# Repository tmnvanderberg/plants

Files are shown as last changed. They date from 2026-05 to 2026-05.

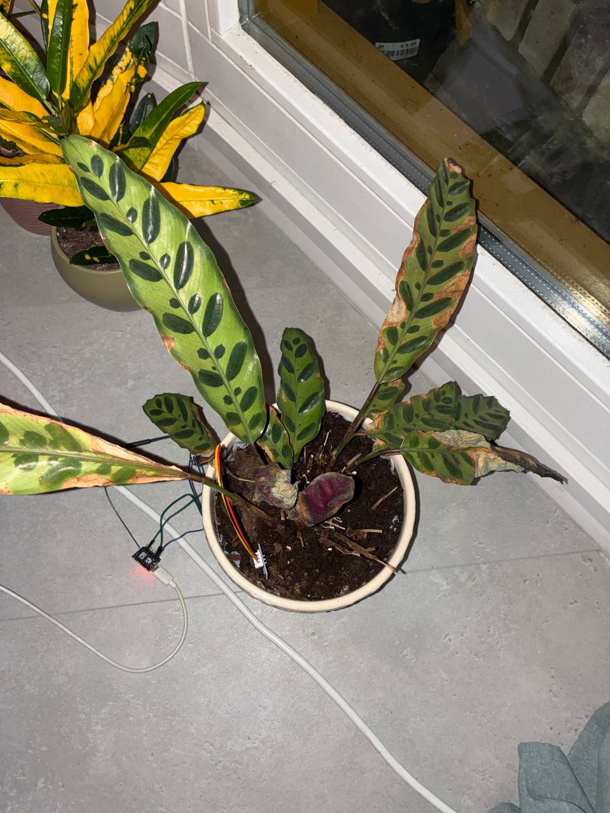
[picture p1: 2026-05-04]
backend/images/plant-node-01.jpg

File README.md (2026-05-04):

# plants

DIY moisture + light monitoring for ~15 plants (10 on a covered Zwolle balcony, ~5 indoors). ESPHome devices reporting to a Pi running Mosquitto + InfluxDB + Grafana.

## Status

**Phase A** — receiver bring-up and BLE-through-windows feasibility test.

## Layout

```
esphome/        device firmware (ESPHome YAML)
  common/       shared config blocks
  receiver.yaml ESP32-WROOM-32 receiver
backend/        Pi services (docker-compose)
docs/           BOM, wiring, phase plans
CLAUDE.md       conventions for LLM-assisted edits
```

## Quick start

### Receiver (Phase A)

```sh
cd esphome
cp secrets.yaml.example secrets.yaml      # fill in WiFi + generated keys
esphome run receiver.yaml                 # initial flash via USB
esphome run receiver.yaml --device plant-receiver.local   # OTA from now on
```

### Backend (Pi)

```sh
cd backend
cp .env.example .env                      # fill in
docker compose up -d                      # or `docker-compose up -d` on Bookworm (apt ships compose v1)
```

Grafana on `:3000`, InfluxDB on `:8086`, Mosquitto on `:1883`.

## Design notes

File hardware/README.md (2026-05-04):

# Hardware design — sensor node

Per-node hardware for the 15× plant monitoring deployment. One identical
node per pot, addressed `plant-node-01` … `plant-node-15`.

## Bill of materials (per node)

| Ref | Part | Notes |
|-----|---|---|
| MCU | ESP32-C3 SuperMini Plus, soldered male headers | 2×8 pin layout, USB-C |
| Light sensor | GY-30 BH1750 module | 1×5 male header replaced with 5-pin JST-XH; see assembly |
| BH1750 cable | JST-XH 5-pin, 5-wire, both ends crimped | stock part |
| Moisture sensor | Capacitive Soil Moisture Sensor with cable (Soldered) | ships with 3-pin cable |
| Battery | 3× AA alkaline holder, integrated switch | nominal 4.5 V, EOL ~3.6 V |
| Carrier PCB | custom, see below | one per node |
| Enclosure | houses carrier + battery holder; BH1750 mounts outside | TBD |

## Power

- 3× AA → carrier `J3` (2-pin JST-PH) → ESP32-C3 `VBUS` pin (silkscreen `5V`).
- C3's onboard LDO (ME6217A33) regulates to 3.3 V; ~150 mV dropout at sleep
  currents holds the rail solid down to a depleted 3.6 V pack.
- Both sensor VCCs share a single switch (not connected to `+3V3` directly):
  - Moisture + BH1750 VCC ← GPIO0 (`SENSOR_PWR`)
  - Combined draw is well under the 40 mA GPIO source limit, so no MOSFET.
- Battery monitor: 1 MΩ / 1 MΩ divider from VBAT to GND, midpoint to GPIO4,
  with 100 nF (`C1`) from the midpoint to GND so the ADC's sample-and-hold
  sees a low AC source impedance.
- USB-C and battery share `VSYS` on the C3. The C3 has a Schottky blocking
  battery → USB-host backfeed, but no diode the other way: with USB plugged
  in **and** the battery switch on, the USB rail will push ~0.2 V into the
  alkaline pack. **Switch the AA holder off (or unplug `J3`) before
  connecting USB.**

## Pin assignment (ESP32-C3)

| GPIO | Net | Function |
|---|-----|---|
| GPIO0 | SENSOR_PWR | shared sensor VCC switch (high = on) |
| GPIO1 | AOUT | moisture analog in (ADC1_CH1, 12 dB attenuation) |
| GPIO4 | VBAT_DIV | battery voltage monitor |
| GPIO5 | SDA | I²C data |
| GPIO6 | SCL | I²C clock |
| 5V (VBUS) | VBAT | battery + |
| GND | GND | battery − |

## Carrier PCB

Small board, lives inside the enclosure. C3 plugs in via female sockets;
all three sensor/battery wires enter through JSTs.

| Ref | Connector | Purpose |
|-----|---|---|
| U1  | 2×8 female header, 2.54 mm | ESP32-C3 SuperMini Plus socket |
| J1  | JST-XH 3-pin, vertical | moisture sensor cable |
| J2  | JST-XH 5-pin, vertical | BH1750 cable |
| J3  | JST-PH 2-pin, vertical | battery |
| R1  | 1 MΩ, 1206 | VBAT divider, top |
| R2  | 1 MΩ, 1206 | VBAT divider, bottom |
| C1  | 100 nF, 0805 | VBAT divider AC bypass (midpoint to GND) |

### J1 — moisture (3-pin JST-XH)

| Pin | Net |
|-----|-----|
| 1 | SENSOR_PWR |
| 2 | GND |
| 3 | AOUT |

### J2 — BH1750 (5-pin JST-XH, straight-through cable)

Pin order matches the GY-30 module silk (`GND ADD SDA SCL VCC`, end to end),
so the JST-XH on the module installs with **pin 1 over the `GND` pad** and
the cable is a stock straight-through.

| Pin | Net | BH1750 module pin |
|-----|-----|---|
| 1 | GND | GND |
| 2 | GND | ADD |
| 3 | SDA | SDA |
| 4 | SCL | SCL |
| 5 | SENSOR_PWR | VCC |

Pin 2 is tied to GND in copper on the carrier → I²C address `0x23`.

### J3 — battery (2-pin JST-PH)

| Pin | Net |
|-----|-----|
| 1 | VBAT |
| 2 | GND |

## Assembly

1. Carrier PCB ordered with PCBA — sockets, JSTs, resistors, and `C1`
   pre-populated.
2. BH1750 module (per node):
   - Remove the existing 1×5 male header.
   - Solder a 5-pin JST-XH male connector onto the same pads, with **pin 1
     over the `GND` pad** (silk: `GND ADD SDA SCL VCC` end to end). Wrong
     orientation will short `SENSOR_PWR` to GND when the rail switches on.
3. ESP32-C3 SuperMini Plus (per node):
   - Remove the always-on red `PWR` LED (`CD1` on the C3 schematic, 0603,
     top edge near the BOOT button) — hot tweezers, hot-air, or alternately
     reflow both pads with an iron and slide it off. Lifting one end of
     `UR7` (the 0201 limiting resistor in series) is equivalent.
   - Without this, the LED draws ~300–500 µA continuously and the 12-month
     battery target is unreachable.
4. ESP32-C3 pressed into `U1` female sockets.
5. Moisture cable plugged into `J1`.
6. BH1750 cable plugged between the module and `J2`; BH1750 mounted on
   the outside of the enclosure.
7. Battery holder plugged into `J3`.

## I²C

- Bus: GPIO5 (SDA) / GPIO6 (SCL).
- Devices: BH1750 at `0x23`.

## Power management

- **Sleep model:** ESPHome `deep_sleep` between reads; expected wake interval 1 hour.
- **Sensors during sleep:** the `SENSOR_PWR` rail is driven low → moisture
  probe and BH1750 module fully unpowered, including their on-module LEDs.
  GPIO0 is RTC-capable on the C3, so the rail stays held low through deep sleep.
- **C3 SuperMini during sleep:** stock board with the `PWR` LED removed (see
  Assembly), no LDO swap. Expected sleep current ~50–200 µA depending on board
  revision; with the LED in place, add ~300–500 µA on top.
- **Target battery life:** 12+ months on 3× AA alkaline, assuming the LED is
  out. With the LED in place: ~6 months.
- **ESPHome side:** both sensors declare a `power_supply:` referencing the
  shared GPIO0 switch. The switch enables the rail, waits for settling, the
  sensors read, then it disables.

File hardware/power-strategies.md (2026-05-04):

# Power strategies — battery node

The current design (`README.md` → Power management) wakes each node every
~1 hour, opens a full WiFi+MQTT session, publishes one reading, and
deep-sleeps. WiFi association dominates radio-on time (~2–5 s out of a
~3–6 s wake), and that's where most of the battery goes.

This document captures two alternative transport/wake models we may
explore if 12-month battery life proves insufficient. Neither is
implemented today. They are not mutually exclusive.

## Baseline (current design)

| | |
|---|---|
| Wake interval | ~1 hour |
| Wake duration | ~3–6 s |
| Radio-on time | ~2–5 s (association + TX) |
| Transport | WiFi → MQTT |
| OTA window | every wake |

## Option A — ESP-NOW to the receiver

Replace WiFi+MQTT on battery nodes with ESP-NOW, an Espressif peer-to-peer
protocol over the WiFi radio that skips the IP stack entirely. Battery
nodes never associate with the AP. They wake, send one packet to
`plant-receiver` by MAC, and sleep. The mains-powered receiver gateways
ESP-NOW packets into MQTT.

| | |
|---|---|
| Wake interval | unchanged (~1 hour) |
| Wake duration | ~300–500 ms (sensor settling dominates) |
| Radio-on time | ~10–50 ms (TX + ack) |
| Transport | ESP-NOW → receiver → MQTT |
| OTA path | separate periodic WiFi wake |

Expected gain: radio-on time per wake drops ~50–100×. Sensor settling
becomes the next bottleneck — moisture and BH1750 each need
~100–200 ms.

### Constraints

- **Same WiFi channel.** Sender and receiver must be on the same channel.
  Easiest fix: lock the AP to a fixed channel.
- **Not in ESPHome core.** Requires a community external component
  (e.g. `esphome-esp-now`). Bumps the "stock components only" rule in
  `CLAUDE.md` — document the rationale inline if adopted.
- **OTA still needs WiFi.** ESP-NOW does not support OTA. Strategies:
  an extra "OTA wake" every Nth cycle (e.g. once a day) that does a full
  WiFi association, or a flag in the receiver's ESP-NOW ack instructing
  the node to associate to WiFi this cycle.
- **Encryption is opt-in.** ESP-NOW supports CCMP with a 16-byte shared
  key. Probably not needed inside a home network, but available.
- **Receiver becomes a gateway.** Add an ESP-NOW → MQTT bridge on
  `plant-receiver` (lambda + stock MQTT publish).

## Option B — Local buffering, daily upload

Sample on the current schedule but don't transmit each reading. Store
readings in RTC slow memory across deep-sleep cycles; once per day, wake
WiFi, drain the buffer to MQTT in one batch, sleep.

| | |
|---|---|
| Sensor wake interval | ~1 hour |
| Sensor wake duration | ~200–400 ms (sensor read + RTC write, no radio) |
| Upload interval | once per 24 h |
| Upload duration | ~3–6 s (one WiFi session) |
| Transport | WiFi → MQTT, batched payload |
| OTA window | once per day |

Expected gain: radio-on time amortised across 24 readings → ~24×
reduction in transport cost. Total battery life depends on the new
sensor-wake / radio-wake ratio.

### Constraints

- **Custom C++ required.** ESPHome has no stock buffered-readings
  component. Implementation is a `globals` array in RTC slow memory
  plus lambdas for write/drain. Bumps "stock only" — document inline.
- **OTA risk.** A bad firmware push only gets one recovery window per
  day. On a battery node the fallback is a USB cable. `CLAUDE.md`
  already flags this for any deep-sleep + OTA design.
- **RTC memory budget.** ESP32-C3 has ~16 KB of slow RTC RAM. 24
  readings × ~16 bytes (timestamp + moisture + light + battery) is well
  under budget, but plan the schema.
- **No real-time monitoring.** A dying plant is invisible until
  tomorrow's upload. Mitigate with thresholds: if any reading crosses a
  critical band, force an immediate WiFi upload that wake.
- **Time sync.** Each buffered reading needs a timestamp. Either store
  `millis()` since boot and reconstruct on the backend, or NTP-sync at
  upload and timestamp future readings going forward.

## Combining

Nothing prevents using both: sample hourly, buffer in RTC, drain once a
day over ESP-NOW. The OTA-window tradeoff still applies (OTA still needs
WiFi). The two stack rather than overlap — A reduces per-transmission
cost, B reduces transmission count.

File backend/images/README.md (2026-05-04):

# Plant photos

Drop images named `<device_name>.jpg` (or `.png`/`.webp`) here. They'll be served
by the `plant-images` container at `http://plant-pi.local:8088/<filename>` and
referenced from the Grafana dashboard's plant-info panel.

Sizing: keep under ~500 KB. The dashboard renders thumbnails at 180 px wide;
anything larger just adds load time without visual benefit.

Examples:
  plant-node-01.jpg   →  http://plant-pi.local:8088/plant-node-01.jpg
  plant-node-02.png   →  http://plant-pi.local:8088/plant-node-02.png

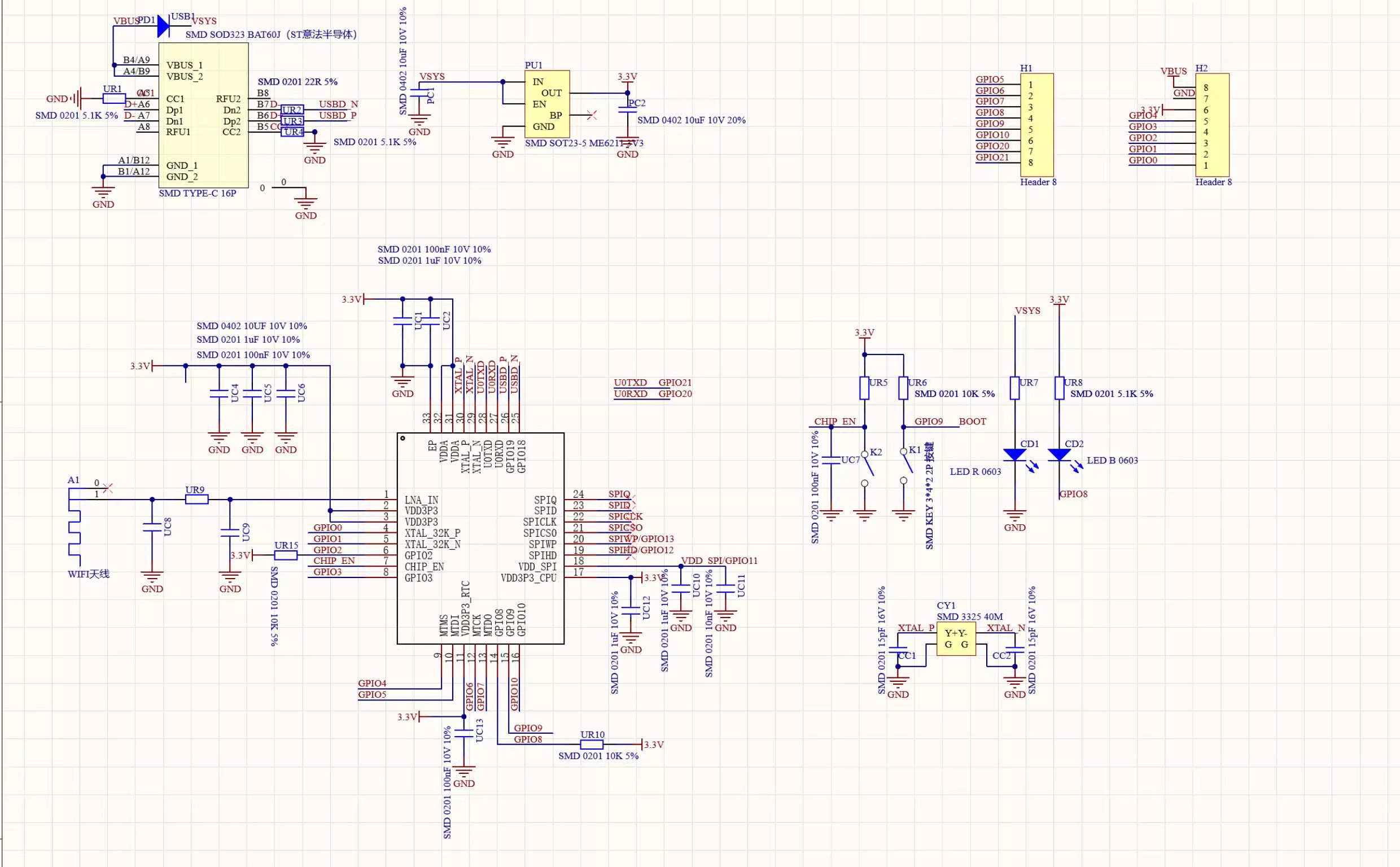
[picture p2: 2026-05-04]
context/007206_schematic_of_the_ESP32-C3_Supermini_plus.jpg

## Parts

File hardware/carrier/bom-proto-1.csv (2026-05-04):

Reference | Qty | Value | DNP | Exclude from BOM | Exclude from Board | Footprint | Datasheet
C1 | 1 | 100nF
J1 | 1 | Moisture
J2 | 1 | Light
J3 | 1 | BAT
R1,R2 | 2 | 1M
U1 | 1 | ESP32

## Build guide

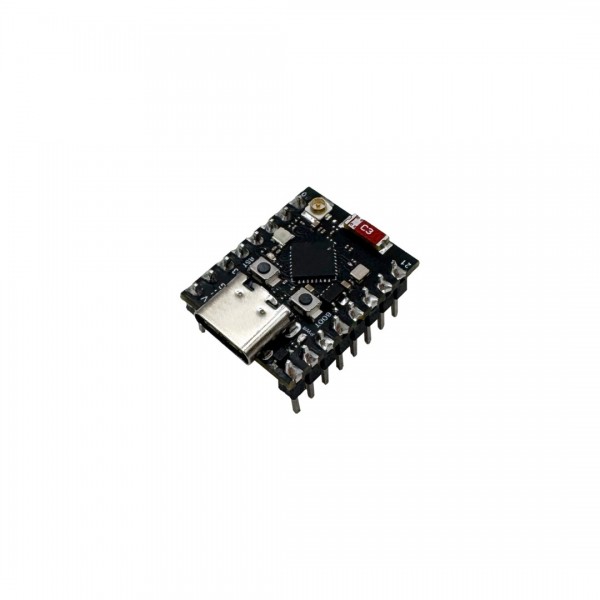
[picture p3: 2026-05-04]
context/ESP32-C3 SuperMini Plus Development Board - Soldered Headers - ESP32C3SMSH_files/esp32-c3-supermini-plus-development-board-with-soldered-headers-600x600.jpg

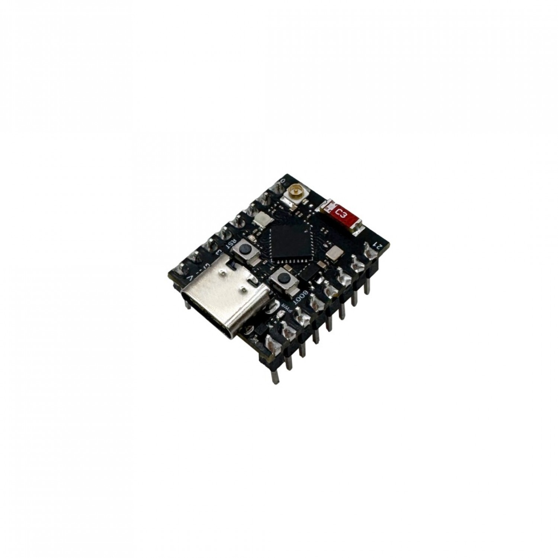
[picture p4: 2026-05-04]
context/ESP32-C3 SuperMini Plus Development Board - Soldered Headers - ESP32C3SMSH_files/esp32-c3-supermini-plus-development-board-with-soldered-headers-1500x1500.jpg

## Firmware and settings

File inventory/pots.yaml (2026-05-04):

# Per-pot inventory + per-species watering profiles.
# Source of truth for dashboard targets, alerting thresholds, and the
# "how much to water" recommendation.
#
# Two parts:
#   1) `profiles` — named reusable profiles, each plant references one
#   2) `pots`     — physical inventory: which board is in which pot, calibration,
#                   profile assignment

# ---------------------------------------------------------------------------
# Profiles
#
# style: cycle
#   The plant prefers a wet-then-dry cycle. We trigger a watering alert when
#   moisture drops below `trigger_water_below_pct`, ask for enough water to
#   reach `saturate_to_pct`, then expect a slow dry-down over a known span.
#   Examples: succulents, ZZ, snake plant, hoya, most cacti.
#
# style: constant
#   The plant prefers steady moisture. We alert if it leaves the
#   `band: [min, max]` for longer than `alarm_window_h`, and recommend a
#   small top-up rather than a deep soak.
#   Examples: ferns, calatheas, fittonia, carnivores (with own water table).
# ---------------------------------------------------------------------------

profiles:

  succulent:
    description: "Cacti, succulents, ZZ, snake plant — full dry-down between waterings."
    style: cycle
    trigger_water_below_pct: 5
    saturate_to_pct: 70
    expected_cycle_days: [10, 28]
    notes: "Roots rot fast if watered while still wet. Err on the dry side."

  drought-tolerant:
    description: "Hoya, peperomia, jade — let dry mostly, not bone-dry."
    style: cycle
    trigger_water_below_pct: 15
    saturate_to_pct: 65
    expected_cycle_days: [7, 14]

  houseplant:
    description: "Most common houseplants — pothos, monstera, philodendron, ficus, dracaena."
    style: cycle
    trigger_water_below_pct: 25
    saturate_to_pct: 65
    expected_cycle_days: [4, 10]
    notes: "Top inch dry → water deeply. Standard 'finger test' equivalent."

  thirsty:
    description: "Tomatoes, basil, mint, peace lily — want regular water, can wilt fast."
    style: cycle
    trigger_water_below_pct: 35
    saturate_to_pct: 70
    expected_cycle_days: [2, 5]

  constant-moist:
    description: "Ferns, calatheas, fittonia — never fully dry."
    style: constant
    band: [50, 75]
    alarm_below_pct: 40
    alarm_above_pct: 80          # post-watering spikes regularly hit 75–80 — only alarm above
    alarm_dry_h:  2              # plant won't wilt in 2h, but trend is real by then
    alarm_wet_h:  24             # root rot is days; brief saturation isn't an emergency
    notes: "Stress shows fast (crispy edges). Mist + steady soil."

  bog:
    description: "Carnivores, rice-paddy plants — sit in saturated medium."
    style: constant
    band: [80, 100]
    alarm_below_pct: 70
    alarm_above_pct: ~           # bog plants don't have an upper limit
    alarm_dry_h:  8
    alarm_wet_h:  ~
    notes: "Distilled / rainwater only for carnivores."

# ---------------------------------------------------------------------------
# Pots
#
# Per pot, fill in:
#   plant         common name
#   species       Latin (optional but useful for sanity-checks)
#   profile       one of the keys under `profiles:` above
#   pot_volume_l  liters of soil — drives watering volume math
#   sensor        per-probe calibration (dry/wet endpoints in volts)
# ---------------------------------------------------------------------------

pots:
  - id: 01
    node: plant-node-01
    mac: e8:3d:c1:85:d0:6c
    plant: Rattlesnake plant
    species: Goeppertia insignis        # formerly Calathea lancifolia
    profile: constant-moist
    pot_volume_l: 1.5                   # rough — measure by filling once for accurate water-volume math
    location: indoor
    sensor:
      dry_v: 2.704
      wet_v: 0.936
    notes: |
      Brown leaf-tips visible at intake = historical winter damage (dry indoor air
      during NL heating season, ~30% RH). With heaters off for spring, new growth
      should come in clean.

      NL tap water is fine for this plant: no residual chlorine, no fluoridation,
      Vitens water in Zwolle is ~8 °dH (moderately soft). Rainwater is a bonus,
      not required. Re-pot every 1–2 years to reset slow mineral accumulation.

      Watch humidity again next October when heaters come back on.

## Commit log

2026-04-27 Bootstrap Phase A receiver and backend stub
    ESPHome receiver config for ESP32-WROOM-32 (Mi Flora block stubbed),
    docker-compose for Mosquitto + InfluxDB + Grafana, BOM/wiring/phase docs,
    and CLAUDE.md conventions for LLM-assisted edits.
2026-05-04 Replace phase/wiring docs with hardware design and plant inventory
    - Drop docs/{BOM,WIRING,PHASE_A,PHASE_B}.md; superseded by hardware/ + inventory/.
    - hardware/README.md: per-node BOM, pin map, carrier PCB, assembly, power.
    - hardware/power-strategies.md: ESP-NOW + daily-batch alternatives if 12-month
    battery life proves insufficient.
    - hardware/carrier/: KiCad project for the carrier PCB.
    - inventory/pots.yaml: per-species watering profiles + per-pot calibration.
    - context/: local snapshots of supplier product pages (ESP32-C3 SuperMini Plus,
    BH1750, capacitive moisture) + ESP32-C3 schematic, kept alongside the design.
    - README.md / CLAUDE.md: drop phase-doc refs; note docker-compose v1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
    [bom-proto-1.csv, carrier.kicad_pcb, carrier.kicad_sch]
2026-05-04 Add ESPHome node-01 — first sensor node bring-up
    - common/node.yaml: shared sensor-node template (i2c on GPIO5/6, MQTT on
    plants/<device>/<sensor>, sensor-power switch on GPIO0, ADC moisture on GPIO1
    with plausibility/spread filters + median, BH1750 at 0x23, RSSI, uptime).
    - node-01.yaml: per-pot calibration substitutions for plant-node-01.
    - base.yaml: bump logger to DEBUG for bring-up visibility.
    - secrets.yaml.example: add mqtt_broker.
2026-05-04 Wire MQTT→InfluxDB ingestion, Grafana provisioning + Telegram alerts, plant images server
    - docker-compose: enable telegraf (MQTT bridge); mount Grafana provisioning
    + pass INFLUX_TOKEN and TELEGRAM_* env; add caddy 'images' service on :8088.
    - .env.example: add TELEGRAM_BOT_TOKEN / TELEGRAM_CHAT_ID with @BotFather setup steps.
    - telegraf/telegraf.conf: subscribe to plants/+/{moisture,moisture_v,light,wifi_rssi,uptime},
    parse device tag from topic, write to InfluxDB sensors bucket.
    - grafana/provisioning/datasources: InfluxDB (Flux, sensors bucket).
    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
